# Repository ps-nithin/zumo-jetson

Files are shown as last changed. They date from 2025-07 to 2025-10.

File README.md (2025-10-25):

# zumo-jetson

A robot that learns and recognizes patterns on the go.

1. The robot is based on Jetson Nano.

2. The demo script reads the camera frames. Masks the blob, here green (for recognizing) and blue (for learning), using color based segmentation by converting the frames to HSV color space. A check is applied to avoid blobs overlapping with the edge of the frame. The masked image is then inputted to pyrebel which learns/recognizes the blob (using https://github.com/ps-nithin/pyrebel#5-pattern-recognition-demo). Here the recognized symbols are mapped with audio recordings made during learning the pattern. The recorded audio is played back during recognition.

3. The robot uses an Arduino Nano RP2040 Connect as motor controller. It is connected to jetson nano over usb. The arduino firmware has common functions to drive motors and leds connected to it. For example, sending "blinkledwhite_1" over serial to the arduino turns on the white led.

4. Three leds (white, green and blue) connected to the arduino shows the current state of the program. The white led blinks when the program is ready to accept input. The green led blinks when a green blob is detected in the input and the program tries to recognize the input. The blue led blinks when a blue blob is detected in the input and the program tries to learn the input. When both the green and the blue led blinks it indicates that both green and blue blobs are present in the input.

5. A speaker and microphone is connected to jetson nano over usb. A Raspberry pi camera module v2 is connected to csi camera port of the jetson nano. Wireless connectivity nor internet is needed to run the program but is used for setting up jetson nano.

# Patterns
The program can handle both green and blue patterns simultaneously. These different combinations of green and blue patterns can occur,

1. Only green patterns are present in the input.
In this case only recognition happens, either in 'image', or 'audio' channel. Channel having higher weightage is selected.

2. Only blue patterns are present.
In this case only learning happens. Since there are no green patterns, all the learning happens in 'audio' channel only. If there are multiple blue patterns, each constituent blue pattern has to be learned seperately in 'audio' channel before learning the pattern as a whole. 

3. Input contains a combination of green and blue patterns.
In this case both learning and recognition happens. The blue patterns are learned with the symbol recognized from reading the green patterns. Both recognizing green patterns and learning blue patterns takes place in channel 'image'.

# Pre-training
Letters of the English alphabets are pre-trained to provide a vocabulary for learning more complex patterns. The pre-trained letters can be relearned later to update the knowbase with different variations of the pre-trained letters as required. 

# Motors
The motors are controlled by four keywords in channel 'image'. 
1. 'fw' for moving forward.
2. 'bw' for moving backward.
3. 'sc' for spinning in clockwise direction.
4. 'sa' for spinning in anti clockwise direction.

These keywords can be reassigned later to any arbitrary pattern you like by relearning.

# Channels
When an image is learned its signatures are stored in channel 'image'. When a recording is made the signatures are stored in channel 'audio'. During recognition, different symbols may be recognized for each channels. The symbol from channel with higher weightage is selected.

# Build
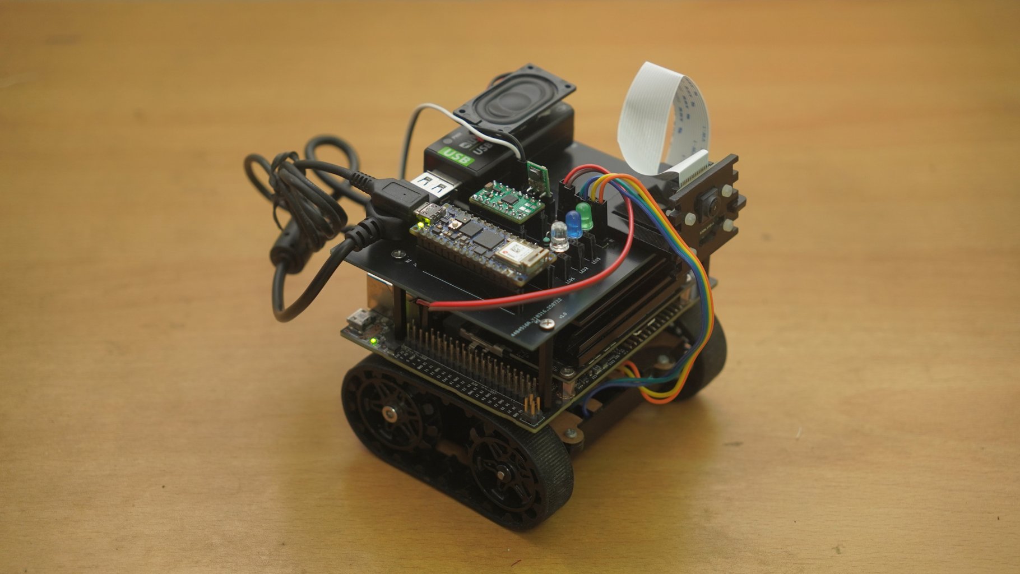
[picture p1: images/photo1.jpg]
<br>

1. Zumo chassis (Pololu - Zumo Chassis Kit (No Motors) https://www.pololu.com/product/1418) act as the main chassis.
2. Motors (Pololu - 298:1 Micro Metal Gearmotor HPCB 6V https://www.pololu.com/product/3069)
3. Motor driver (Pololu - DRV8833 Dual Motor Driver Carrier https://www.pololu.com/product/2130)
4. Voltage regulator (Pololu - 5V Step-Up/Step-Down Voltage Regulator S9V11F5 https://www.pololu.com/product/2836)
5. Arduino Nano RP2040 connect as motor controller
6. Raspberry Pi Camera v2 for camera with acrylic camera mount
7. USB microphone
8. USB speaker
9. USB Wifi dongle / AC8265 Wireless NIC for Jetson Nano for wifi
10. Standoffs and PCBs for structure holding the components
11. Powered by 4xAA batteries.

You could hook up the wires using schematic or there is a robot controller <a href="docs/photo-pcb.jpg">board</a> (please find design files in `docs/zumo-jetson-pcb`).

# Setup
Tested to run on a Jetson Nano with Jetpack 4.6.1.
1. Update packages<br>
`sudo apt update`<br>
`sudo apt upgrade`<br>

2. Install jetson-utils
https://github.com/dusty-nv/jetson-utils

3. Install miniforge with https://github.com/conda-forge/miniforge#unix-like-platforms-macos-linux--wsl<br>
     Numba is installed inside miniforge environment.<br>
     Run the following commands to install numba,<br>
     `source $HOME/miniforge3/bin/activate`<br>
     `conda install python=3.8`<br>
     `conda install -c numba numba`<br>
     
     Copy `jetson-utils` library files from `/usr/lib/python3.6/dist-packages/` to `$HOME/miniforge3/lib/python3.8/site-packages`<br>

     `python3 -m pip install pyserial`<br>
     `python3 -m pip install scipy`<br>
     `python3 -m pip install sounddevice`<br>
     `sudo apt install libportaudio2 espeak-ng`<br>
    
4. Install pyrebel<br>
   `cd`<br>
   `git clone https://github.com/ps-nithin/pyrebel`<br>
   `cd pyrebel`<br>
   `python3 -m pip install .`<br>
   
   Patterns can also be learned using `pyrebel/demo/pyrebel_main_learn_multiple.py` (https://github.com/ps-nithin/pyrebel#5-pattern-recognition-demo).<br>
   For example, images in zumo-jetson/scripts/images/train-hand/ are learned to learn English vocabulary.<br>
   `python3 pyrebel_main_learn_multiple.py --learn images/train-hand/`

You may also need to change the microphone and speaker settings.

# Running the script
1. Demo script 1 - Single pattern<br>
`cd`<br>
`git clone https://github.com/ps-nithin/zumo-jetson`<br>
`cd zumo-jetson/scripts`<br>
`sudo $HOME/miniforge3/bin/python3 pyrebel_main_learn_sound_jetson.py --camera 1 --user=$USERNAME`<br>

2. Demo script 2 - Multiple patterns<br>
`cd`<br>
`git clone https://github.com/ps-nithin/zumo-jetson`<br>
`cd zumo-jetson/scripts`<br>
`sudo $HOME/miniforge3/bin/python3 pyrebel_main_learn_sound_jetson_multiple.py --camera 1 --user=$USERNAME`<br>

# Running the script on startup
`sudo cp zumo-jetson.service /etc/systemd/system/`<br>
`sudo systemctl daemon-reload`<br>
`sudo systemctl enable zumo-jetson.service`<br>
`sudo systemctl start zumo-jetson.service`<br>

If everything went right you should see the white led blinking!

# Demo
1. https://youtu.be/uzXOSZ4ztho Intro
2. https://youtu.be/M06xsy5dlf4 Motor control

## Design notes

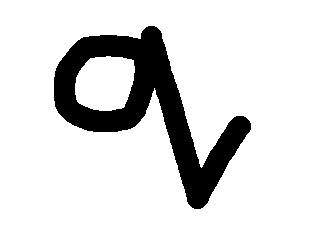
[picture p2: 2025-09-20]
scripts/images/train-hand/q.png

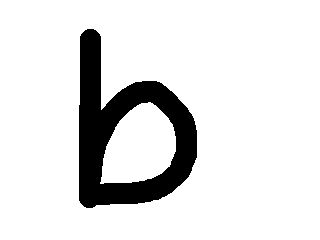
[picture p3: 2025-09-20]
scripts/images/train-hand/b.png

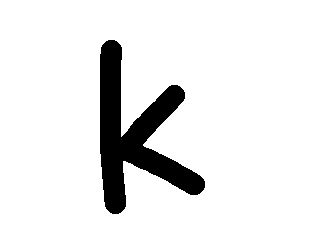
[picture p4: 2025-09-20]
scripts/images/train-hand/k.png

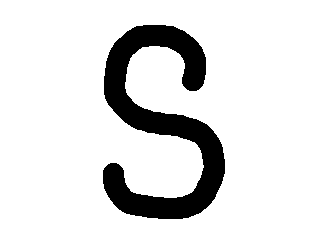
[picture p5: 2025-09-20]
scripts/images/train-hand/s.png

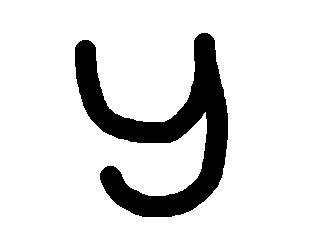
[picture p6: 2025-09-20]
scripts/images/train-hand/y.png

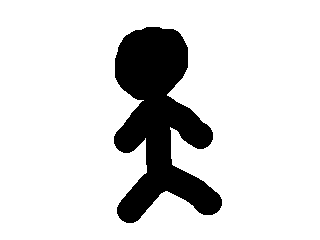
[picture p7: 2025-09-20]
scripts/images/train-hand/human-pose.png

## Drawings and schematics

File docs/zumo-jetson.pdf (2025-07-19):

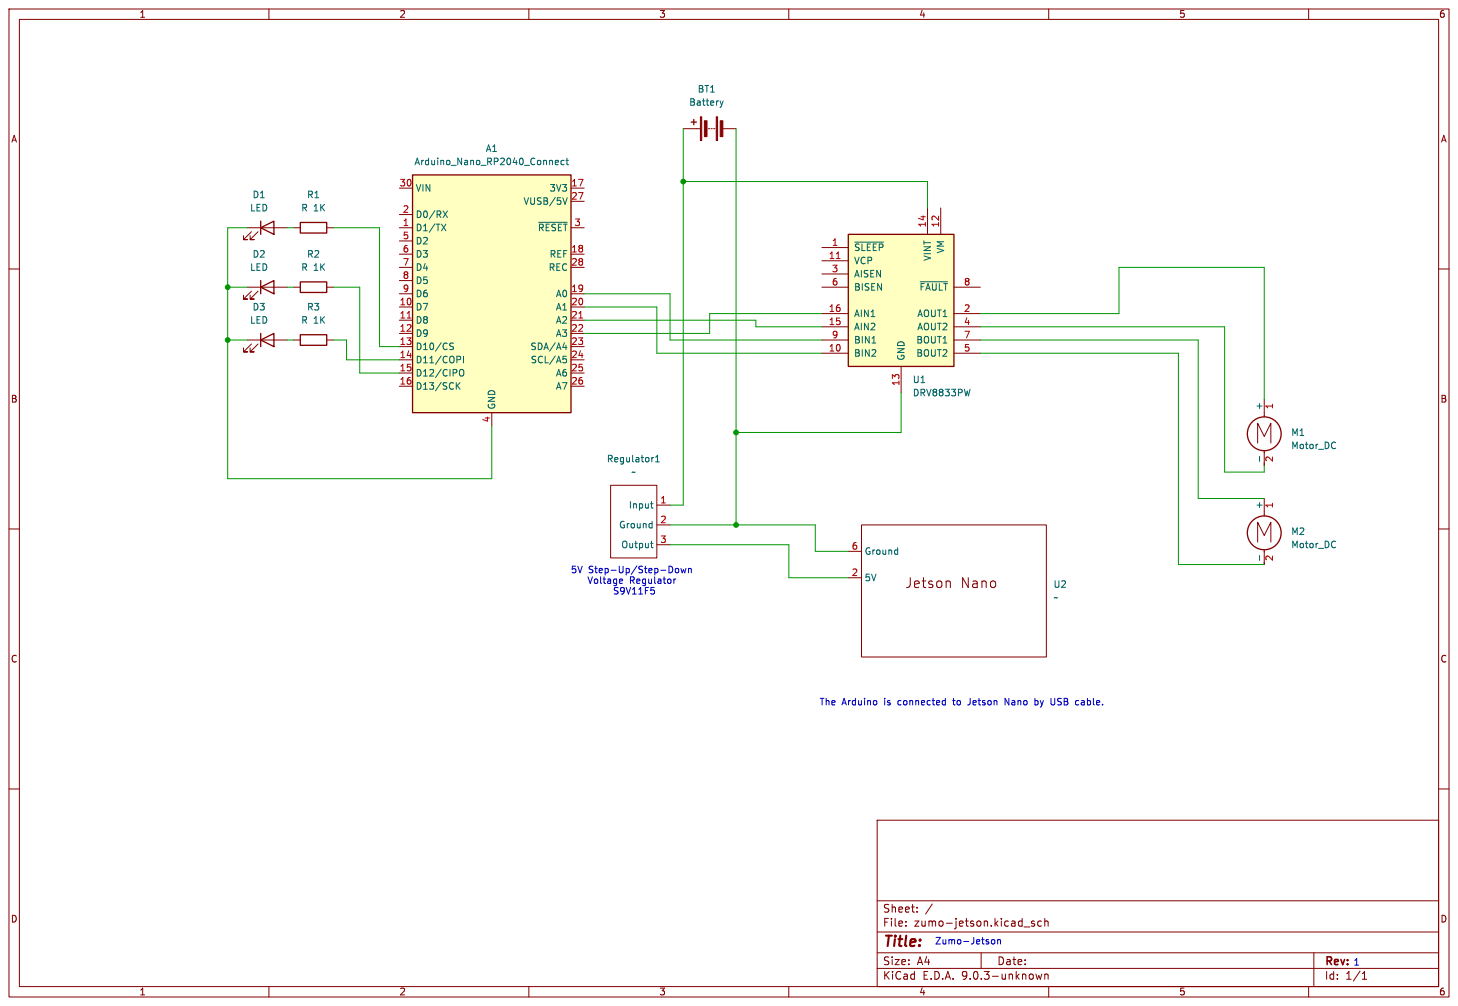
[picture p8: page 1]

5V Step-Up/Step-Down

Id: 1/1 Title: File: zumo-jetson.kicad_sch Sheet: /

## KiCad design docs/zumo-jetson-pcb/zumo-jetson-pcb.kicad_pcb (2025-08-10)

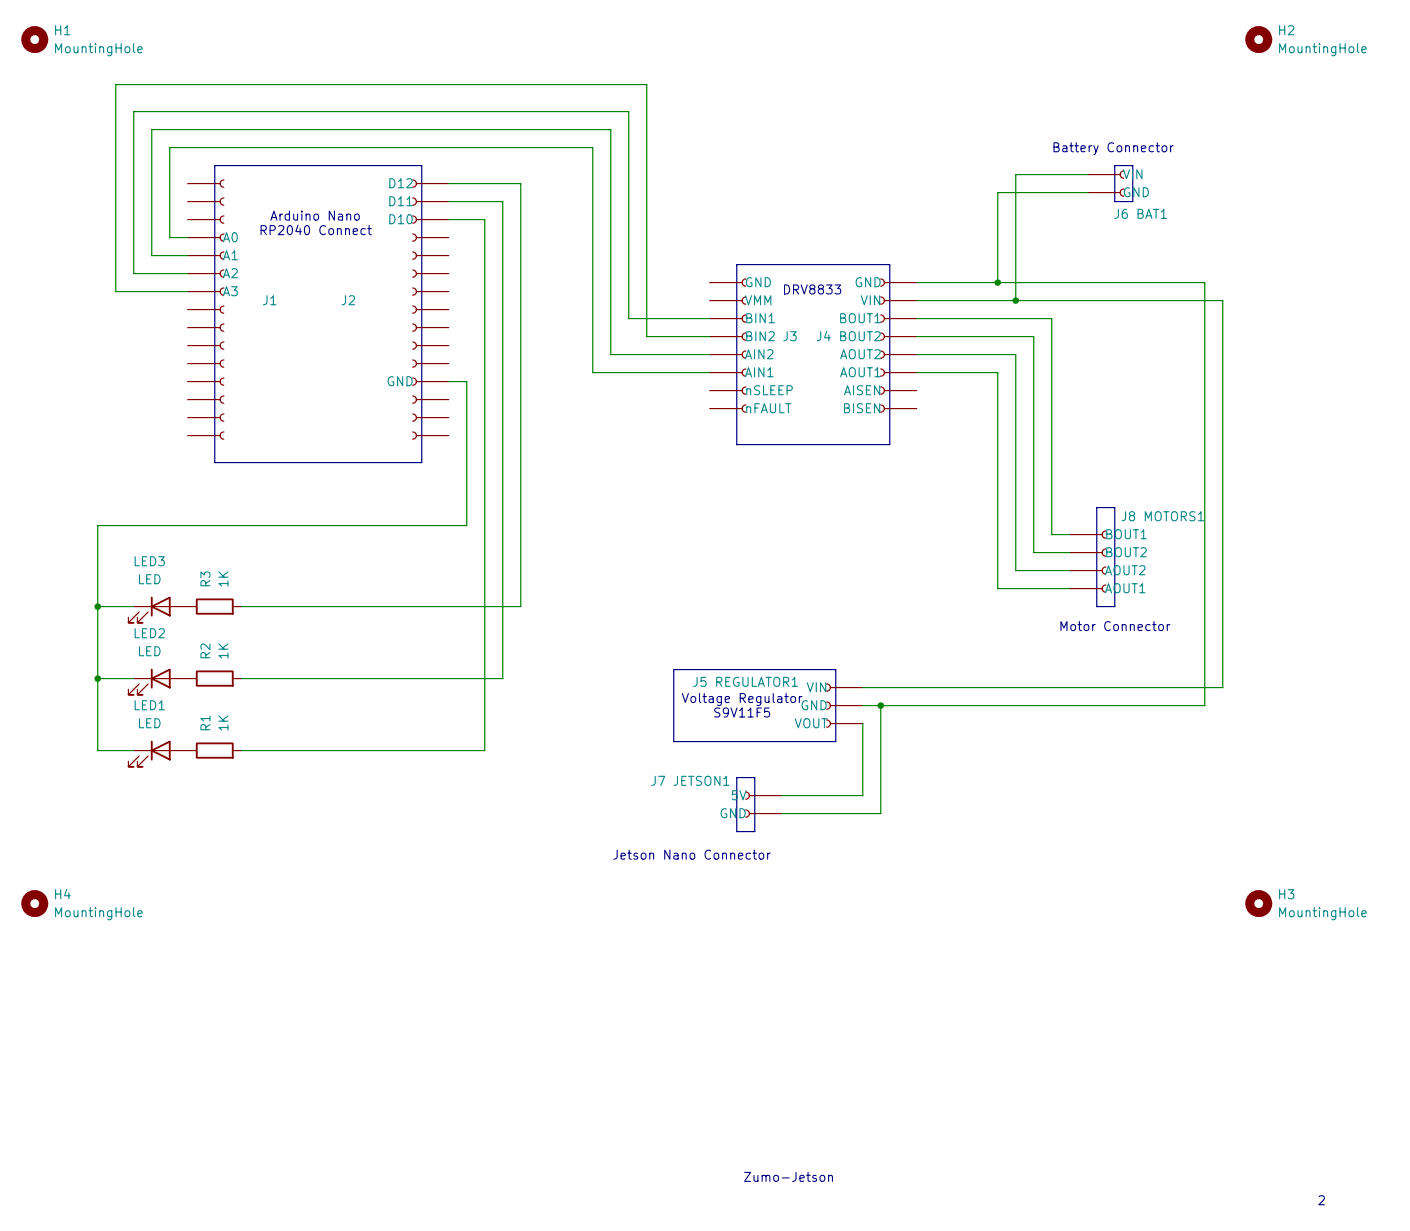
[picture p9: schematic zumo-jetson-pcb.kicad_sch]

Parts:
H1, H2, H3, H4: MountingHole; MountingHole_2.7mm_M2.5
J1, J2: Conn_01x15_Socket; PinSocket_1x15_P2.54mm_Vertical
J3, J4: Conn_01x08_Socket; PinSocket_1x08_P2.54mm_Vertical
J5 REGULATOR1: Conn_01x03_Socket; PinSocket_1x03_P2.54mm_Vertical
J6 BAT1, J7 JETSON1: Conn_01x02_Socket; PinHeader_1x02_P2.54mm_Vertical
J8 MOTORS1: Conn_01x04_Socket; PinHeader_1x04_P2.54mm_Vertical
LED1, LED2, LED3: LED; PinSocket_1x02_P2.54mm_Vertical
R1, R2, R3: 1K; R_Axial_DIN0204_L3.6mm_D1.6mm_P2.54mm_Vertical

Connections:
unnamed: J1.4 (A0), J3.6 (AIN1)
unnamed: J1.5 (A1), J3.5 (AIN2)
unnamed: J1.6 (A2), J3.3 (BIN1)
unnamed: J1.7 (A3), J3.4 (BIN2)
unnamed: J2.3 (D10), R1.2
unnamed: J2.2 (D11), R2.2
unnamed: J2.1 (D12), R3.2
unnamed: J2.12 (GND), LED1.1 (K), LED2.1 (K), LED3.1 (K)
unnamed: J4.6 (AOUT1), J8 MOTORS1.4 (AOUT1)
unnamed: J4.5 (AOUT2), J8 MOTORS1.3 (AOUT2)
unnamed: J4.3 (BOUT1), J8 MOTORS1.1 (BOUT1)
unnamed: J4.4 (BOUT2), J8 MOTORS1.2 (BOUT2)
unnamed: J4.1 (GND), J5 REGULATOR1.2 (GND), J6 BAT1.2 (GND), J7 JETSON1.2 (GND)
unnamed: J4.2 (VIN), J5 REGULATOR1.1 (VIN), J6 BAT1.1 (VIN)
unnamed: J5 REGULATOR1.3 (VOUT), J7 JETSON1.1 (5V)
unnamed: LED1.2 (A), R1.1
unnamed: LED2.2 (A), R2.1
unnamed: LED3.2 (A), R3.1

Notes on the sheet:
Arduino Nano RP2040 Connect
Voltage Regulator S9V11F5
Battery Connector
Motor Connector
Zumo-Jetson
Jetson Nano Connector
DRV8833

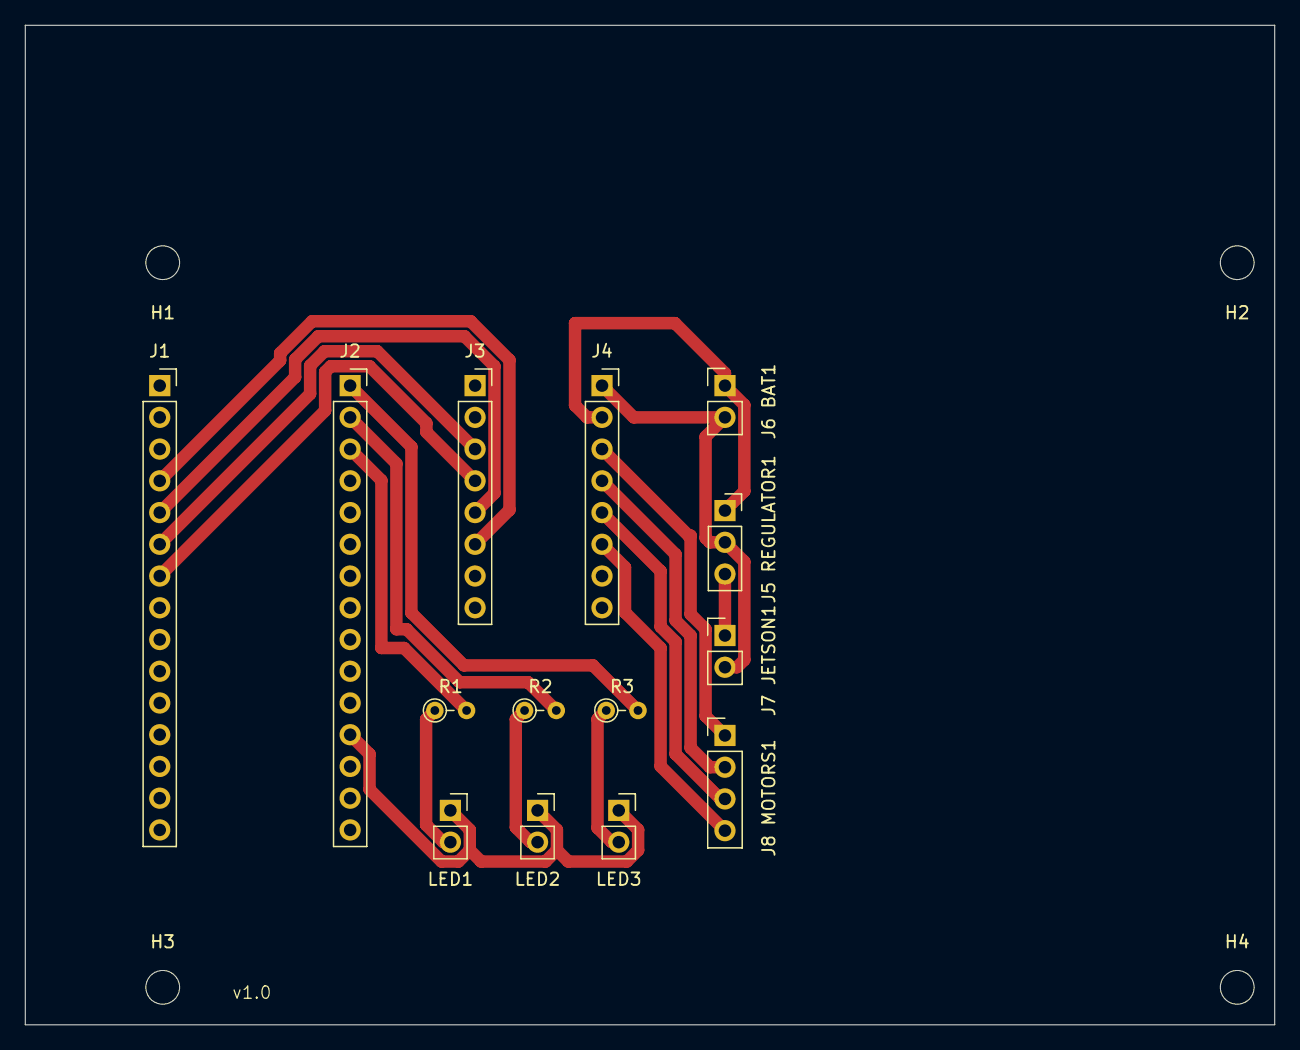
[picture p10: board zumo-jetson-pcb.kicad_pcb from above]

Board: 2 copper layers, 100.0 x 80.0 mm, 18 parts (0 on the bottom side), 18 nets.

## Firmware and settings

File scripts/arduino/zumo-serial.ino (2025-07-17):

/*
# Copyright (C) 2024-2025 Nithin PS.
# This file is part of Pyrebel.
#
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
# Pyrebel is distributed in the hope that it will be useful, but WITHOUT ANY WARRANTY; 
# without even the implied warranty of MERCHANTABILITY or FITNESS FOR A PARTICULAR 
# PURPOSE. See the GNU General Public License for more details.
#
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
*/


#include <Arduino_LSM6DSOX.h>

float Ax, Ay, Az;
float Gx, Gy, Gz;

unsigned long last_call=millis();
const int greenLedPin=12;
const int blueLedPin=11;
const int whiteLedPin=10;

const long interval = 250;
int greenLedState=LOW;
int blueLedState=LOW;
int whiteLedState=LOW;
unsigned long greenLedPreviousMillis = 0;  // will store last time LED was updated
unsigned long blueLedPreviousMillis = 0;  // will store last time LED was updated
unsigned long whiteLedPreviousMillis = 0;  // will store last time LED was updated
int flipGreen=HIGH;
int flipBlue=HIGH;
int flipWhite=HIGH;

void on_led_sub(int val){
  if(val==0){
    digitalWrite(LED_BUILTIN,LOW);   // blink the led
  }else if (val==1){
    digitalWrite(LED_BUILTIN,HIGH);
  }
}

void on_led_green_sub(int val){
  if(val==0){
    digitalWrite(greenLedPin,LOW);   // blink the led
    greenLedState=0;
  }else if (val==1){
    digitalWrite(greenLedPin,HIGH);
    greenLedState=1;
  }
}

void on_led_blue_sub(int val){
  if(val==0){
    digitalWrite(blueLedPin,LOW);   // blink the led
    blueLedState=0;
  }else if (val==1){
    digitalWrite(blueLedPin,HIGH);
    blueLedState=1;
  }
}

void on_led_white_sub(int val){
  if(val==0){
    digitalWrite(whiteLedPin,LOW);   // blink the led
    whiteLedState=0;
  }else if (val==1){
    digitalWrite(whiteLedPin,HIGH);
    whiteLedState=1;
  }
}

void on_motor_ctrl_sub1(int speed){
  last_call=millis();
  if (speed>0){
    analogWrite(A1,LOW);
    analogWrite(A0,speed);  
  }else{
    analogWrite(A0,LOW);
    analogWrite(A1,-speed);
  }  
  delay(500);
  stop_zumo();
}

void on_motor_ctrl_sub2(int speed){
  last_call=millis();
  if (speed>0){
    analogWrite(A3,LOW);
    analogWrite(A2,speed);  
  }else{
    analogWrite(A2,LOW);
    analogWrite(A3,-speed);
  }  
  delay(500);
  stop_zumo();
}

void on_zumo_move(int speed){
  last_call=millis();
  if (speed>0){
    analogWrite(A1,LOW);
    analogWrite(A0,speed);
    analogWrite(A3,LOW);
    analogWrite(A2,speed);  
  }else{
    analogWrite(A0,LOW);
    analogWrite(A1,-speed);
    analogWrite(A2,LOW);
    analogWrite(A3,-speed);
  }  
  delay(500);
  stop_zumo();
}

void on_zumo_spin(int speed){
  last_call=millis();
  if (speed>0){
    analogWrite(A1,LOW);
    analogWrite(A0,speed);
    analogWrite(A3,speed);
    analogWrite(A2,LOW);  
  }else{
    analogWrite(A0,LOW);
    analogWrite(A1,-speed);
    analogWrite(A2,-speed);
    analogWrite(A3,LOW);
  }  
  delay(500);
  stop_zumo();
}
void stop_zumo(){
  analogWrite(A0,LOW);
  analogWrite(A1,LOW);
  analogWrite(A2,LOW);
  analogWrite(A3,LOW);
}

void setup()
{ 
  pinMode(LED_BUILTIN, OUTPUT);
  pinMode(A0,OUTPUT);
  pinMode(A1,OUTPUT);
  pinMode(A2,OUTPUT);
  pinMode(A3,OUTPUT);
  pinMode(greenLedPin,OUTPUT);
  pinMode(blueLedPin,OUTPUT);
  pinMode(whiteLedPin,OUTPUT);
  if (!IMU.begin()) {
    while (1);
  }
  Serial.begin(115200);
}

void loop()
{ 
  /*
  if (IMU.accelerationAvailable()) {
    IMU.readAcceleration(Ax, Ay, Az);
  }

  if (IMU.gyroscopeAvailable()) {
    IMU.readGyroscope(Gx, Gy, Gz);
  }   
  */
  if(millis()-last_call>2000){
    stop_zumo();    
  }
  if (Serial.available() > 0) {
    String state = Serial.readStringUntil('\n');
    if (state.startsWith("moveforward_")) {
      int speed = state.substring(12).toInt();
      on_zumo_move(speed);
    } else if (state.startsWith("movebackward_")) {
      int speed = state.substring(13).toInt();
      on_zumo_move(-speed);   
    } else if (state.startsWith("spincw_")) {
      int speed = state.substring(7).toInt();
      on_zumo_spin(speed);   
    } else if (state.startsWith("spinacw_")) {
      int speed = state.substring(8).toInt();
      on_zumo_spin(-speed);          
    } else if (state.startsWith("blinkled_")) {
      int status = state.substring(9).toInt();
      on_led_sub(status);         
    } else if (state.startsWith("blinkledgreen_")) {
      int status = state.substring(14).toInt();
      on_led_green_sub(status);          
    } else if (state.startsWith("blinkledblue_")) {
      int status = state.substring(13).toInt();
      on_led_blue_sub(status);          
    } else if (state.startsWith("blinkledwhite_")) {
      int status = state.substring(14).toInt();
      on_led_white_sub(status);          
    }
  }
  
  if (greenLedState==HIGH){
    unsigned long greenLedCurrentMillis = millis();
    if (greenLedCurrentMillis - greenLedPreviousMillis >= interval) {
      // save the last time you blinked the LED
      greenLedPreviousMillis = greenLedCurrentMillis;
      if (flipGreen){
        digitalWrite(greenLedPin,HIGH);
        flipGreen=LOW;
      }else{
        digitalWrite(greenLedPin,LOW);
        flipGreen=HIGH;
      }
    }
  }
  if (blueLedState==HIGH){
    unsigned long blueLedCurrentMillis = millis();
    if (blueLedCurrentMillis - blueLedPreviousMillis >= interval) {
      // save the last time you blinked the LED
      blueLedPreviousMillis = blueLedCurrentMillis;
      if (flipBlue){
        digitalWrite(blueLedPin,HIGH);
        flipBlue=LOW;
      }else{
        digitalWrite(blueLedPin,LOW);
        flipBlue=HIGH;
      }
    }
  }
  if (whiteLedState==HIGH){
    unsigned long whiteLedCurrentMillis = millis();
    if (whiteLedCurrentMillis - whiteLedPreviousMillis >= interval) {
      // save the last time you blinked the LED
      whiteLedPreviousMillis = whiteLedCurrentMillis;
      if (flipWhite){
        digitalWrite(whiteLedPin,HIGH);
        flipWhite=LOW;
      }else{
        digitalWrite(whiteLedPin,LOW);
        flipWhite=HIGH;
      }
    }
  }
  delay(1);
}

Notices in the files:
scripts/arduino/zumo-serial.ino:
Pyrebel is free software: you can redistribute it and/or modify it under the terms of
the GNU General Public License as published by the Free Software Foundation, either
